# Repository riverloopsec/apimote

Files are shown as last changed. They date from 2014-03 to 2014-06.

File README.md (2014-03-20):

apimote
=======

ApiMote IEEE 802.15.4/ZigBee Sniffing Hardware

The ApiMote v4beta version is beta hardware intended for researchers,
students, utility companies, etc. to use for learning about and 
evaluating the security of IEEE 802.15.4/ZigBee systems as authorized.

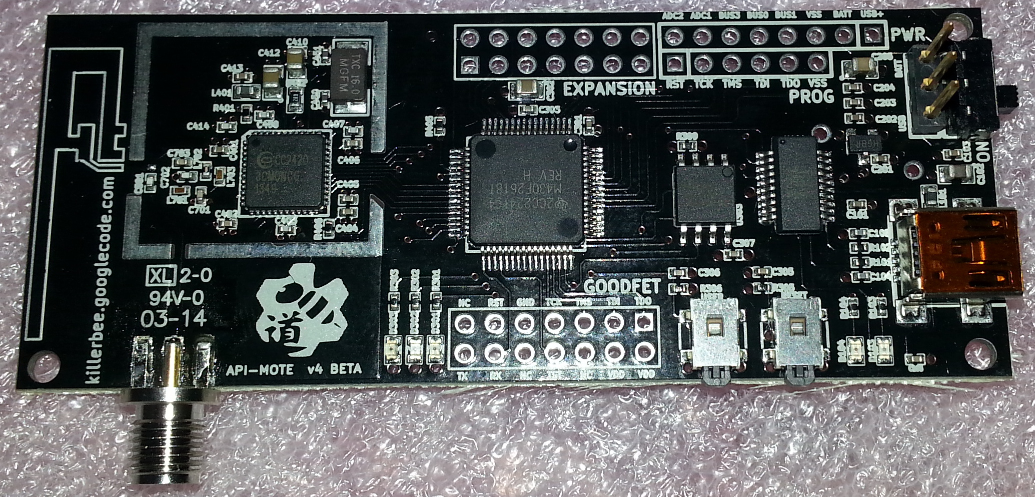
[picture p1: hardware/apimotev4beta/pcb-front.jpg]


----

The design files are created in KiCad, and we reccomend opening them in
the latest version.

----
Copyright 2013-2014 River Loop Security, LLC
Released as Open-Source Hardware under the LICENSE.txt terms.
You *must* use this hardware (and any accompanying software) as authorized
by law, and it is provided pursuint to those terms. We *are not* responsible
for any unauthorized or illegal use of this research tool.

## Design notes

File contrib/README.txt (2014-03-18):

We welcome contributions, additions, etc.

The ApiMote is specifically designed to expose pins for
both the microcontroller as well as power planes to allow
for expanded capabilities such as "shields" and battery packs.

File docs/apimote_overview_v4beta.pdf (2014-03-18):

Api-Do Project

# Api-Mote

Base r4.0beta

February 4, 2014

## 1 Product Description

Api-Mote is a low-power wireless module supporting IEEE 802.15.4. It allows for rapid application prototyping as well as wireless and security research. It leverages industry-standard chips including the MSP430 microprocessor and an IEEE 802.15.4 and ZigBee-ready RF transceiver. These main ICs provide a mix of ease-of-use/development with common wireless RF and security research frameworks as well as low-level hardware access (such as provided by the CC2420 compared to other models). Capability for expansion is designed into the Api-Mote Base , with two expansion headers, a battery-board/expansion header, and the option of an internal (PCB) or external (SMA-connected) antenna.

## 2 Key Features

- 2.4 GHz IEEE 802.15.4 Compliant and ZigBeeTMReady RF Transceiver (CC2420)
- Interoperability with other IEEE 802.15.4 devices
- 16-Bit Ultra-Low-Power MCU (116kB Flash, 8KB RAM) (MSP430F2618), featuring Integrated ADC, DAC, Supply Voltage Supervisor, and DMA Controller
- FTDI USB-to-Serial IC
- Programming and data collection via USB
- Integrated onboard antenna
- Low current consumption
- Hardware link-layer encryption and authentication is supported
- Optional SMA antenna connector
- Basic GoodFET-based firmware support is already available (TinyOS support should be easy)

## Contents

1 Product Description | 1
2 Key Features | 1
3 Module Description | 3
4 Microprocessor | 3
5 Radio | 6
6 Memory | 7
7 Expansion Connectors | 7
8 License | 8
9 Ordering/Contact Information | 8


Figure 1: Api-Mote Base 4.0beta Front

## 3 Module Description

The Api-Mote features a number of components in the standard board population, which is depicted in Figures 1 and 2:

### 3.1 Block Diagram

The Api-Mote Base standard components and their logical connections are shown at a highlevel in Figure 3:

## 4 Microprocessor

### 4.1 Description

The Api-Mote Base uses a TI MSP430F2618 micro-controller, part of the MSP430 family of ultralow-power micro-controllers. The architecture has five low-power modes optimized to achieve extended battery life in portable applications. The device features a powerful 16-bit RISC CPU, 16-bit registers, and constant generators. The calibrated digitally controlled oscillator (DCO) allows wake-up from low-power modes to active mode in less than 1 s. The MSP430F261x series has two built-in 16-bit timers, a fast 12-bit A/D converter, a comparator, dual 12-bit D/A converters, four universal serial communication interface (USCI) modules, DMA, and up to 64 I/O pins. Of these, up to 48 are available on the Api-Mote Base as I/O pins, as the rest are for dedicated functions (JTAG, Vdd/Vss, crystals, etc).
For more detailed information on the micro-controller, please refer to http://www.ti.com/
product/msp430f2618. (http://www.ti.com/product/msp430f2618)

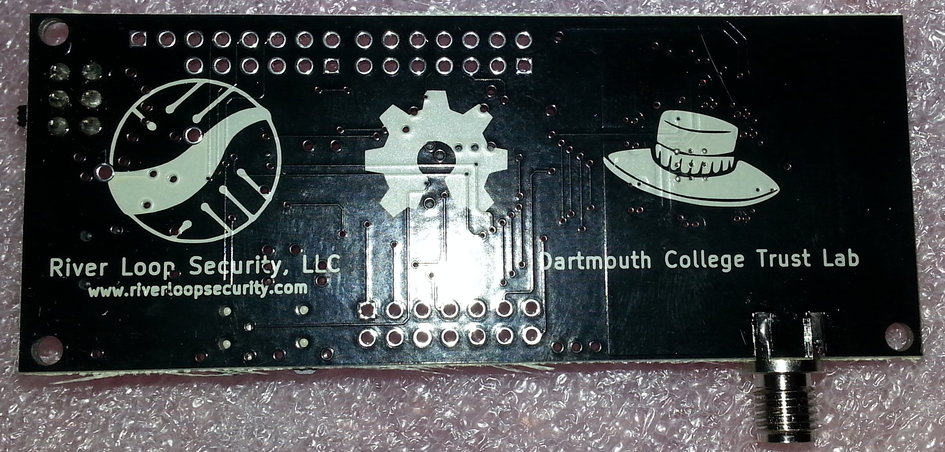
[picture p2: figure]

Figure 2: Api-Mote Base 4.0beta Back

### 4.2 Computer Communication

The Api-Mote uses an FTDI USB controller to communicate with the host computer. In order to communicate with the Api-Mote , the FTDI drivers must be installed on the host. These are often installed by default, but otherwise can be downloaded from FTDI’s website at: http://www.ftdichip.com. The Api-Mote appears as a COM port in Windows’ device manager or as a device in /dev in Linux, OSX, etc (see lsusb or dmesg). An application may communicate with the Api-Mote by opening the COM port or serial device assigned to the Api-Mote . Api-Mote communicates with the host computer through USART1 on the TI MSP430.
The Api-Mote uses a modern FTDI chip, and a newer Linux kernel is needed for built-in support. If you’re using Linux and you see the device in lsusb but don’t see the device appear in /dev/ttyUSB*, then this may be the issue. We’ve tested with 3.2.0-26-generic (on Ubuntu 12.04) among other kernels.

### 4.3 Programming

The Api-Mote revision 4.0beta can be wired either with direct access to chip programming using the FTDI DTR and RTS pins tied to the TCLK and RST pins on the MSP430, or may instead use an optional PIC micro-controller with special code to enable programming mode on the MSP430 after receiving a special command sequence. Unless otherwise specified, we discuss the Api-Mote Base with the direct programming mode. This is most closely compared to the GoodFET41’s wiring for programming (but with a different UART being used). Firmware images must be programmed and compiled for this specific architecture and hardware layout/pins. The programming is intended to be done using the patched BSL loader in the GoodFET trunk. Bootloading can be invoked as follows:

./goodfet.bsl --speed=38400 -p apimote4.hex

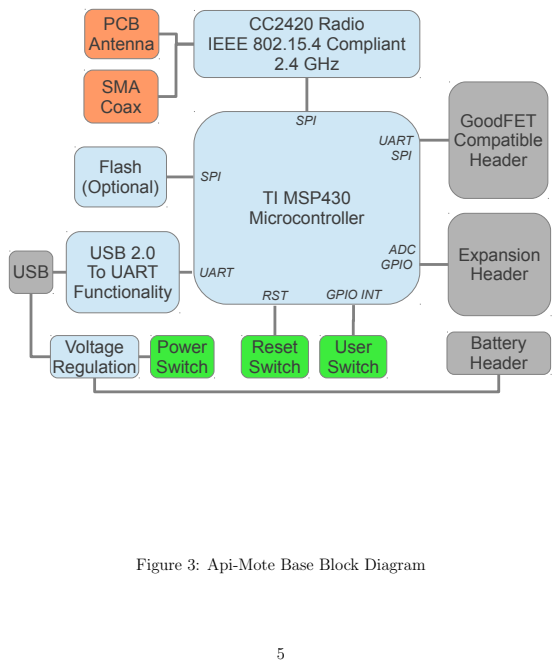
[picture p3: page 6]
CC2420 Radio IEEE 802.15.4 Compliant 2.4 GHz; PCB Antenna; SMA Coax; TI MSP430 Microcontroller; USB 2.0 To UART Functionality; Flash (Optional); GoodFET Compatible Header; Expansion Header; Reset Switch; User Switch; Power Switch; SPI; UART SPI; ADC GPIO UART; RST; GPIO INT; Voltage Regulation; USB; Battery Header

Figure 3: Api-Mote Base Block Diagram

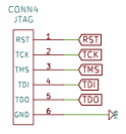
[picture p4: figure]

Figure 4: Programming/JTAG Header

If you need to compile modifications to the firmware, we show the compilation of the GoodFET trunk firmware for this board as an example:

$ cd goodfet/trunk/firmware
$ export board=apimote2
$ make clean install
$ ../client/goodfet.bsl --speed=38400 -p goodfet.hex

Note: The firmware for ApiMote 2, 3, and 4 is currently the same. Although currently compiled with board set to apimote2, the firmware is optimized for Api-Mote 4.0beta boards. They should work on ApiMote r2, boards, with the exception of the 3 user LEDs being controlled backwards (off turns them on, and visa versa).

### 4.3.1 Advanced Programming Access

The Api-Mote Base provides a programming header offering access to the MSP430’s JTAG pins, as shown in Figure 4.

## 5 Radio

Api-Mote features the Chipcon CC2420 radio for wireless communications. The CC2420 is an IEEE 802.15.4 compliant radio providing the PHY and some MAC functions.
The CC2420 is highly configurable for many applications with the default radio settings providing IEEE 802.15.4 compliance. It also has programmable output power. More information on the CC2420 is available in Chipcon’s datasheet at http://www.ti.com/product/
cc2420. (http://www.ti.com/product/cc2420)
The CC2420 is controlled by the TI MSP430 micro-controller through the SPI port and a series of digital I/O lines and interrupts. The radio may be shut off by the micro-controller for low power duty cycled operation.
The CC2420 provides a digital received signal strength indicator (RSSI) that may be read any time. Also, on each packet reception, the CC2420 samples the first eight chips, calculates

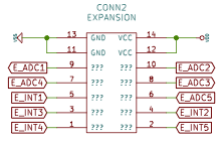
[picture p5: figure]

Figure 5: Expansion Header

the error rate, and produces a link quality indication (LQI) value that may optionally be included with each received packet.

## 6 Memory

The Api-Mote Base has support for external memory (rather than what is contained in the MCU), specifically a flash chip mounted on the board. This is available by SPI, and is specified as a 32M flash IC. Currently, support for this chip is not in the GoodFET firmware. Please feel free to add it! Note, it is connected on a separate SPI bus than the radio.

## 7 Expansion Connectors

The Api-Mote Base has three expansion connectors. These are detailed below:

### 7.1 Expansion Header

The Api-Mote Base provides a 7-by-2 header meant to enable additional external devices such as sensors, LCD displays, user I/O, and peripherals can be controlled. The pinout of this header is shown in Figure 5.

### 7.2 GoodFET Header

The Api-Mote Base provides a 7-by-2 header that is intended to be compatible with the headers common on GoodFET boards. GoodFET firmware images which seek this compatibility should setup this header as shown in Figure 6.

### 7.3 Battery Header

The Api-Mote Base is designed to operate on battery power, and has a 8-by-1 header to support the addition of a custom battery pack that provides advanced power regulation,

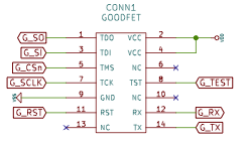
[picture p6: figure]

Figure 6: GoodFET Header

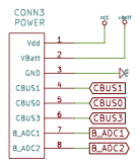
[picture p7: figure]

Figure 7: Battery Header

sleep, and recharge capabilities. The pinout of this header is shown in Figure 7. The Api-Mote Base USB-to-serial IC supports high current USB port detection for decreased charge time. At this time, Api-Mote Base revision 4.0beta does not yet have a complementary battery pack, but one is under development.

## 8 License

This product is released by River Loop Security as an open-source project. The hardware designs and firmware are freely available. However, we ask that one does not sell products based on this device without first obtaining written permission. Collaboration, however, is always welcome and we strongly encourage people to help develop the firmware, etc. Please contact us if you have questions.

## 9 Ordering/Contact Information

To request an Api-Mote, please visit http://rmspeers.com/contact/pcb-requests. For more information, please contact us at team@riverloopsecurity.com.

## Acknowledgements

The Api-Mote Base project lead, Ryan Speers, extends many thanks to the board engineer and designer, Javier Vazquez, as well as the original Api-Mote v1 engineer. Also, much credit and thanks goes to Professor Sergey Bratus of Dartmouth College for his encouragement and funding of the test runs of production. Thank you to River Loop Security for supporting this project with time and funding. Finally, thanks goes to Travis Goodspeed, Ricky Melgares, and Michael Ossmann for their ongoing collaboration with hardware and ZigBee security research.

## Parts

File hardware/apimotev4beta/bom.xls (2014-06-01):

Quantity | Reference(s) | Footprint | Value | Mfg | Mfg Part | Notes
2 | C701, C703 | SM0402 | 0.5pF | AVX | 04025A0R5CAT2A
2 | C501, C702 | SM0402 | 5.6pF | AVX | 04025U5R6CAT2A
1 | J101 | CUSTOM | N/A | FCI | 10033526-N3212MLF
1 | ANT1 | RP-SMA | N/A | Amphenol | 132136RP | Optional part; or Molex 73391-0320
2 | SW305, SW306 | SPST NO M | N/A | TE Connectivity / Alcoswitch | 1571262-2
1 | JMP201 | SIL-3 (0.1”) | N/A | FCI | 69190-403
1 | Y450 | SM2010 | 16MHz | TXC | 7A-16.000MAAJ-T
1 | L702 | SM0402 | 5.6nH | Abracon | ATFC-0402-5N6-B-T
2 | L101, L401 | SM0603 | 600R/2A | Murata | BLM18KG601SN1D
4 | C205, C302, C410, C412 | SM0805 | 10uF | TDK | C2012X5R1A106K125AB and C2012X5R1A106K/1.25
1 | U401 | QFN-48 | N/A | TI | CC2420
2 | C104, C105 | SM0402 | 47pF | TDK | CGA2B2C0G1H470J
2 | R101, R102 | SM0402 | 27R | Bourns | CR0402-JW-270GLF
1 | R309 | SM0402 | 10K | Visahy | CRCW040210K0JNED
5 | R305, R306, R401, R405, R406 | SM0402 | 43K 1% | Visahy | CRCW040243K0FKED
1 | R402 | SM0603 | 2R | Visahy | CRCW06032R00JNTA / CRCW06032R00JNEA
1 | U101 | SSOP-20 | N/A | FTDI | FT231XS-R
2 | C450, C451 | SM0402 | 27pF | Murata | GRM1555C1H270GA01D
4 | C403, C407, C408, C414 | SM0402 | 68pF | Murata | GRM1555C1H680JA01D
2 | C201, C202 | SM0402 | 1uF | Murata | GRM155R61A105KE15D
12 | C101, C103, C203, C204, C301, C303, C307, C401, C404, C405, C406, C413 | SM0402 | 0.1uF | Murata | GRM155R71A104JA01D
2 | C305, C306 | SM0402 | 2.2nF | Murata | GRM155R71H222KA01D
2 | L701, L703 | SM0402 | 7.5nH | Murata | LQP15MN7N5B02D
1 | U201 | SOT-23A | N/A | Microchip | MCP1702T-3302E/CB
5 | R103, R104, R301, R302, R303 | SM0402 | 330R | Rohm Semiconductor | MCR01MRTF3300
1 | SW201 | SIL-3 (0.1”) | N/A | Apem | MHSS1105
1 | JMP202 | 0.1” Pitch | N/A | Adam Tech | MSA-G
1 | U301 | QFP-64 | N/A | TI | MSP430F2618TPM
Opt | U303 | SOIC-8 | N/A | Microchip | SST25VF032B-80-4I-S2AF | Optional part
2 | C106, C402 | SM0402 | 10nF | Visahy | VJ0402Y103JXXCW1BC
1 | C102 | SM0805 | 4.7uF | Visahy | VJ0805V475MXQTW1BC
2 | D103, D302 | SM0603 | GREEN | Visahy | VLMG1300-GS08
2 | D104, D303 | SM0603 | RED | Visahy | VLMS1300-GS08
1 | D301 | SM0603 | YELLOW | Visahy | VLMY1300-GS08
Opt | Headers | 1 row strips |  | 3M | 929834-02-36-RK
Opt | Headers | 2 x 7 pins |  | 3M | 929836-01-07-RK
1 | JMP202 | 2 PIN SHUNT

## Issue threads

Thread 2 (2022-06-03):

how to connect to kali with apimote

Jungjungjungjung, 2022-06-03:
hi , i have installed the killerbee in my kali linux and connect the apimote to my laptop . the issue is when i run zbid , it wont show the apimote that i connected
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

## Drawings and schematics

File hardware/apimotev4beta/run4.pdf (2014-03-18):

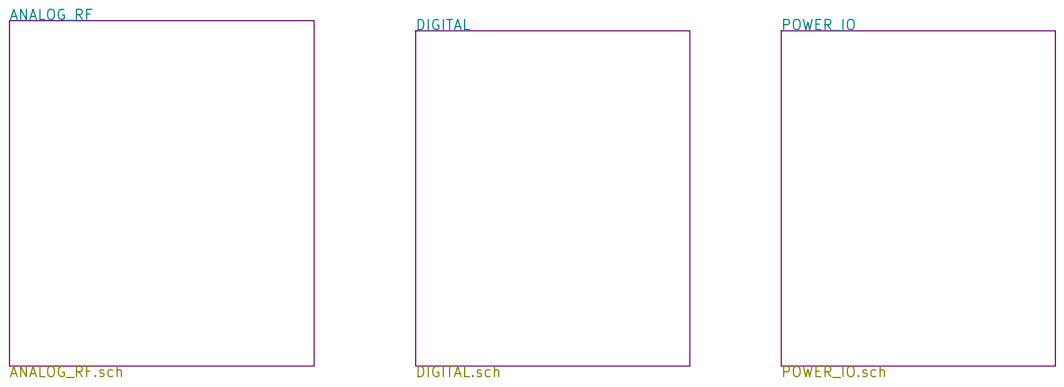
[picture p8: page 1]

POWER_IO.sch DIGITAL DIGITAL.sch ANALOG_RF ANALOG_RF.sch

C Sheet: /home/devops/Dropbox/apimote/run4-kicad/run4.sch File: Title:

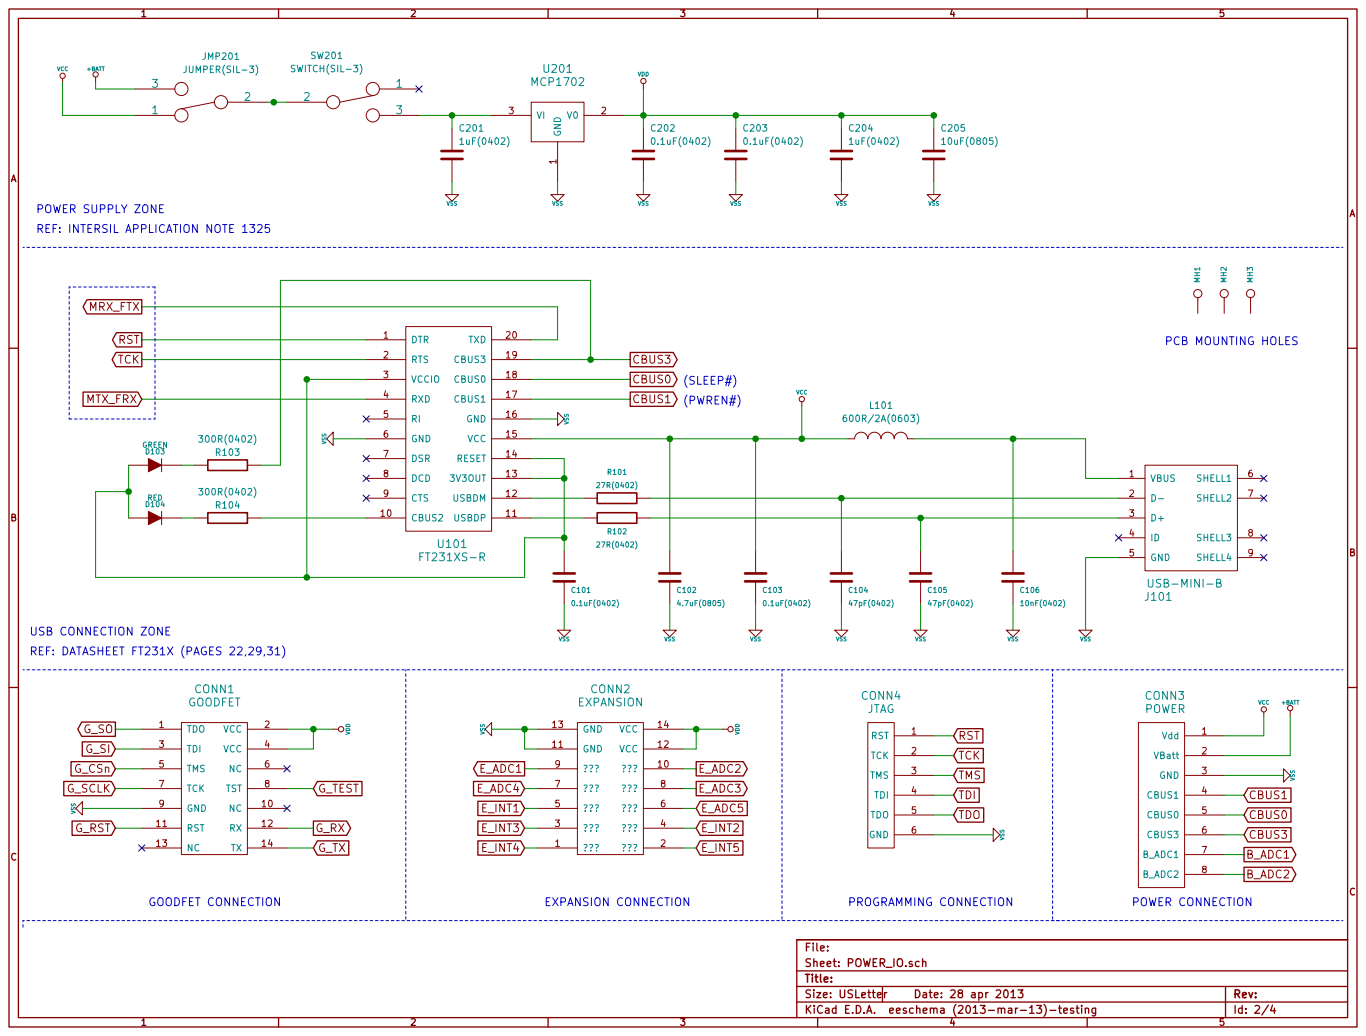
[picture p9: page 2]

C Sheet: POWER_IO.sch File: Title:

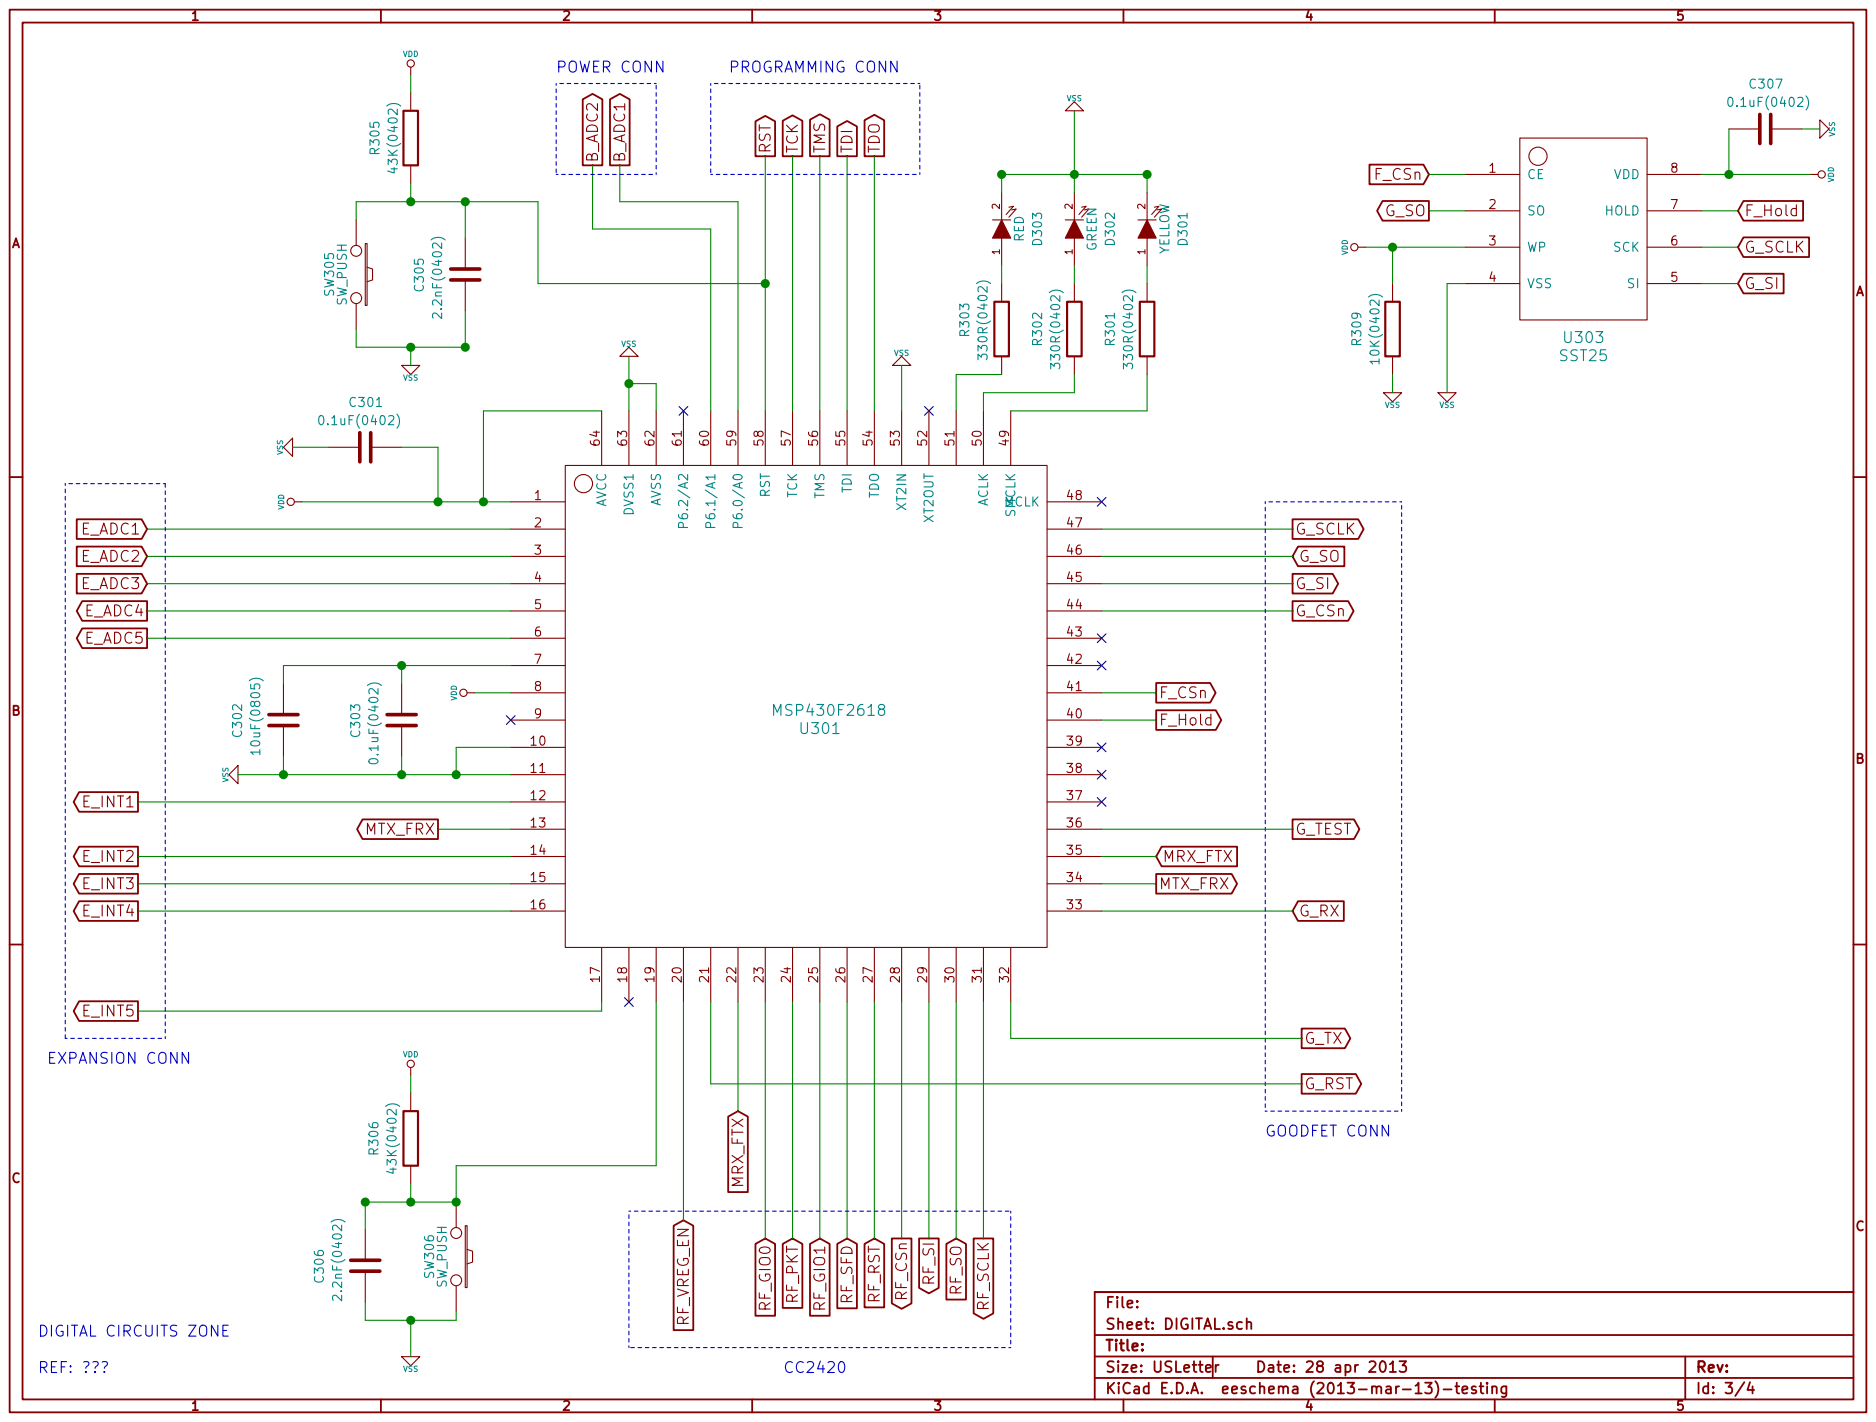
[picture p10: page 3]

C Sheet: DIGITAL.sch File: Title:

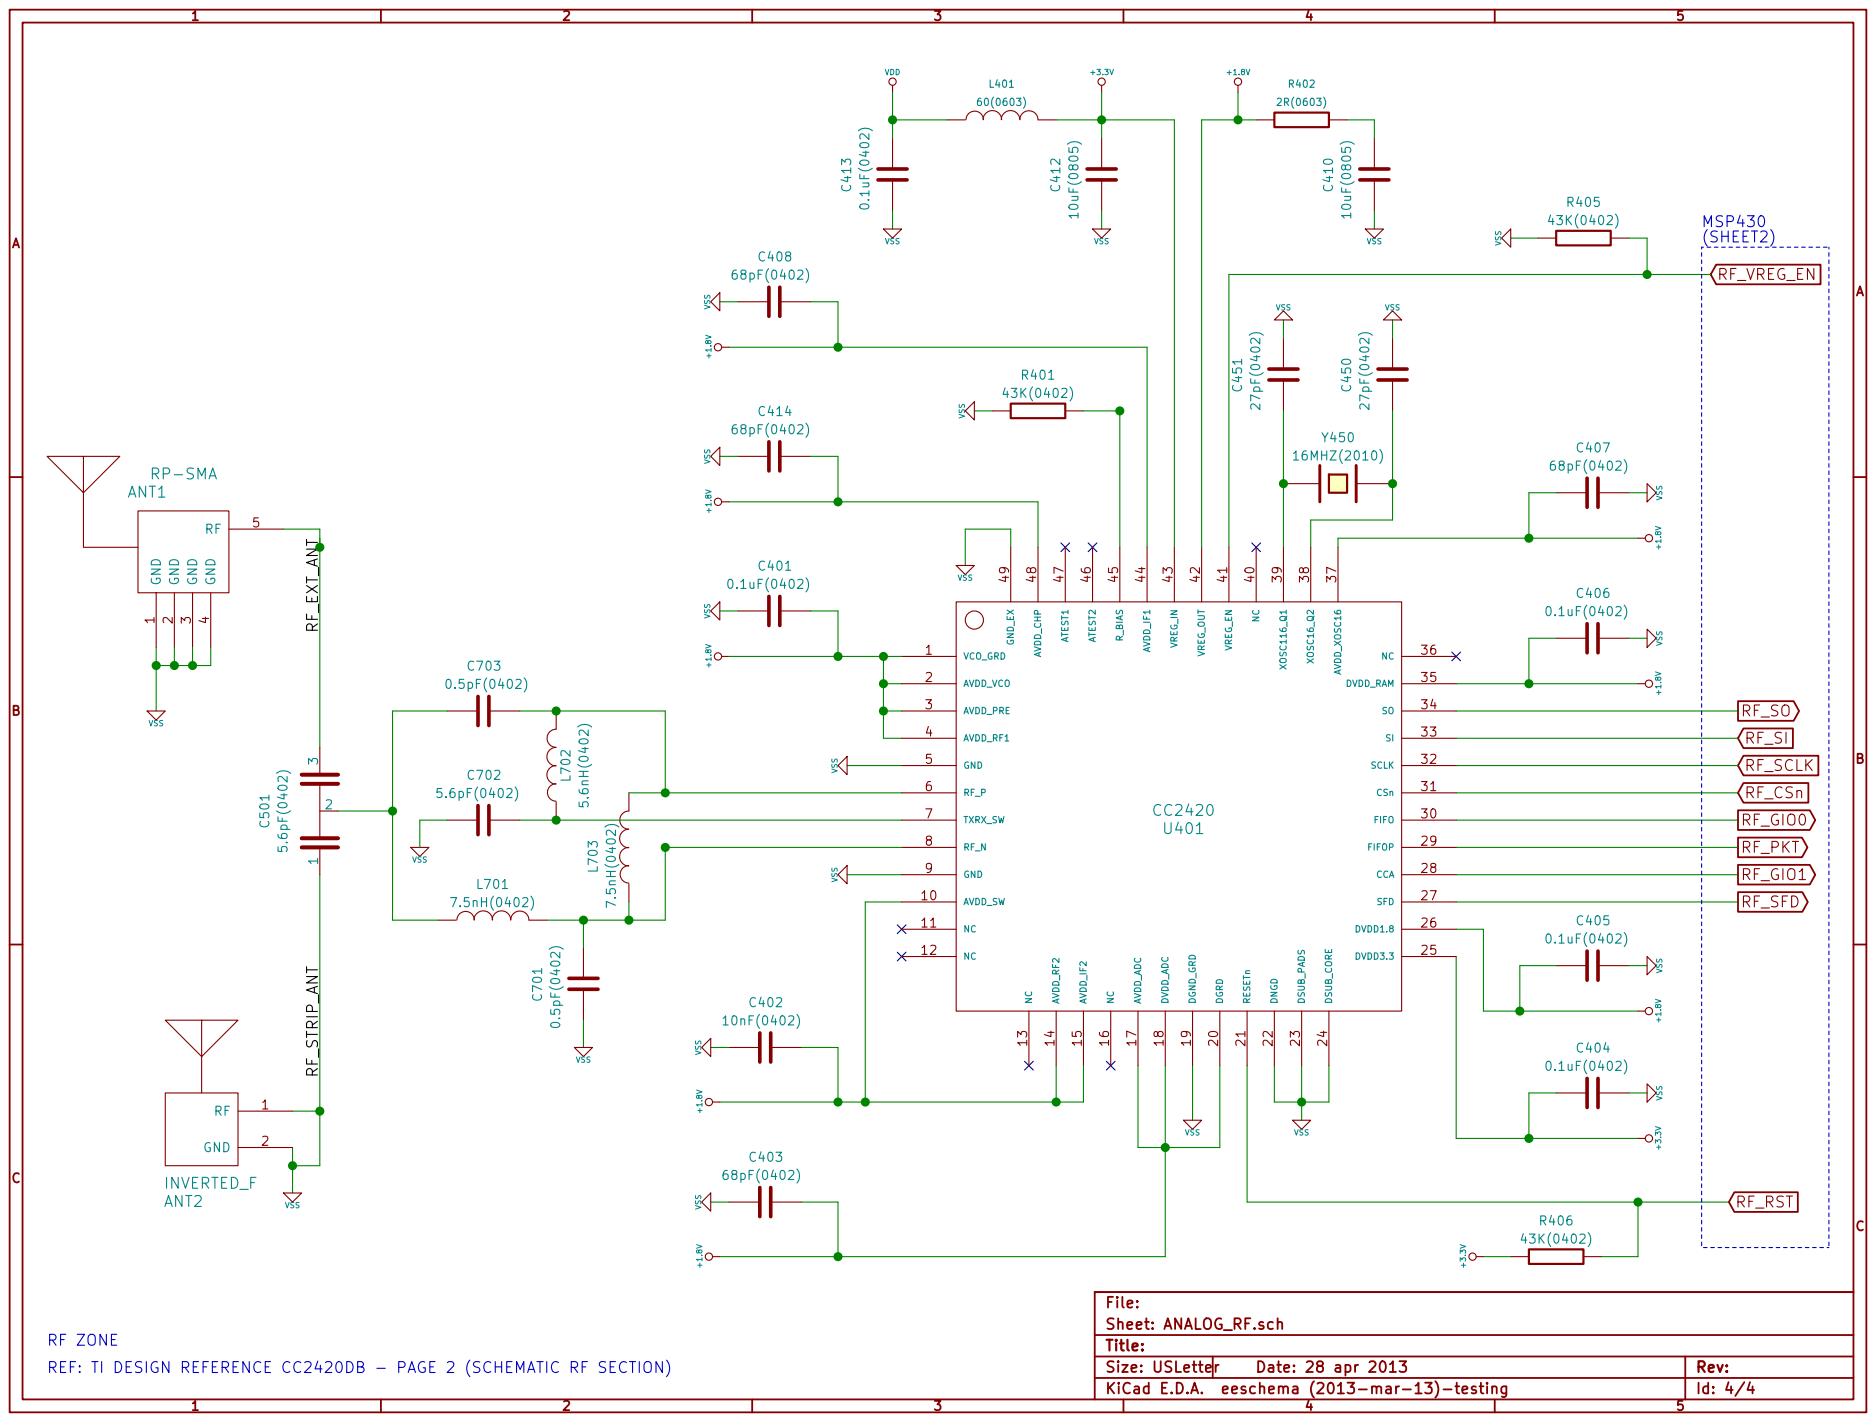
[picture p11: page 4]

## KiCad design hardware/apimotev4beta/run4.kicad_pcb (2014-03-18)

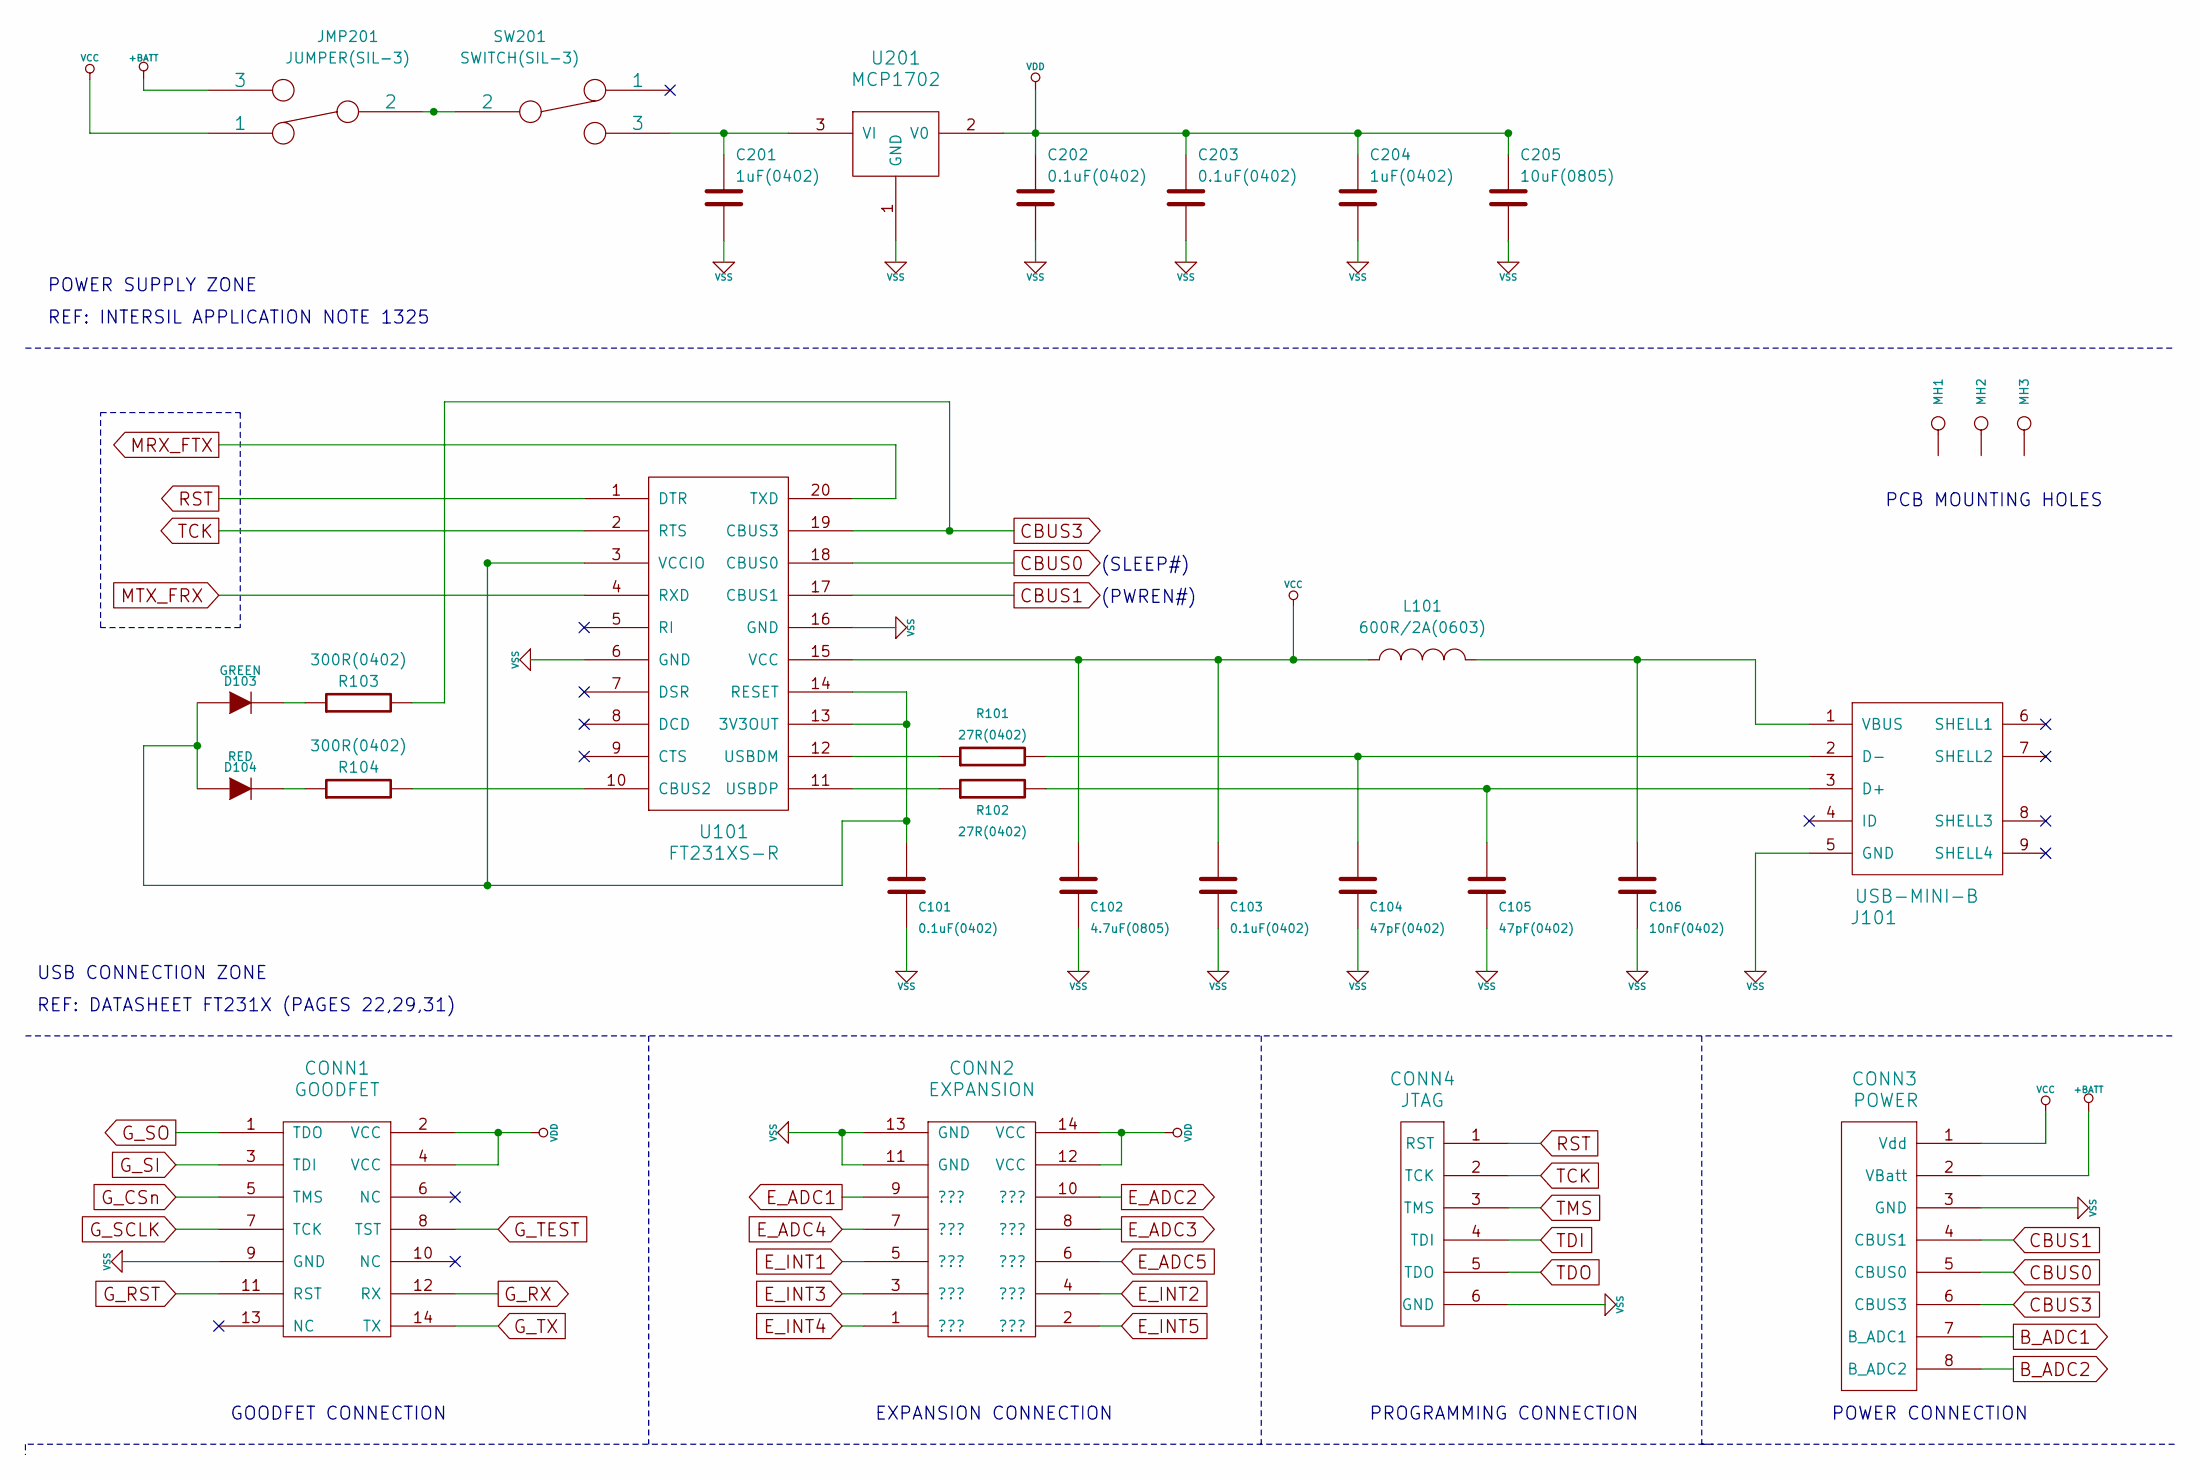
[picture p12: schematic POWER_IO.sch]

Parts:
C101, C103: 0.1uF(0402)
C102: 4.7uF(0805)
C104, C105: 47pF(0402)
C106: 10nF(0402)
C201, C204: 1uF(0402)
C202, C203: 0.1uF(0402)
C205: 10uF(0805)
CONN1: GOODFET
CONN2: EXPANSION
CONN3: POWER
CONN4: JTAG
D103: GREEN
D104: RED
J101: USB-MINI-B
JMP201: JUMPER(SIL-3)
L101: 600R/2A(0603)
MH1, MH2, MH3: Xmm
R101, R102: 27R(0402)
R103, R104: 300R(0402)
SW201: SWITCH(SIL-3)
U101: FT231XS-R
U201: MCP1702

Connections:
+BATT: CONN3.2 (VBatt), JMP201.3
B_ADC1: CONN3.7 (B_ADC1); also elsewhere on the board
B_ADC2: CONN3.8 (B_ADC2); also elsewhere on the board
CBUS0: CONN3.5 (CBUS0), U101.18 (CBUS0)
CBUS1: CONN3.4 (CBUS1), U101.17 (CBUS1)
CBUS3: CONN3.6 (CBUS3), R103.2, U101.19 (CBUS3)
E_ADC1: CONN2.9 (???); also elsewhere on the board
E_ADC2: CONN2.10 (???); also elsewhere on the board
E_ADC3: CONN2.8 (???); also elsewhere on the board
E_ADC4: CONN2.7 (???); also elsewhere on the board
E_ADC5: CONN2.6 (???); also elsewhere on the board
E_INT1: CONN2.5 (???); also elsewhere on the board
E_INT2: CONN2.4 (???); also elsewhere on the board
E_INT3: CONN2.3 (???); also elsewhere on the board
E_INT4: CONN2.1 (???); also elsewhere on the board
E_INT5: CONN2.2 (???); also elsewhere on the board
G_CSn: CONN1.5 (TMS); also elsewhere on the board
G_RST: CONN1.11 (RST); also elsewhere on the board
G_RX: CONN1.12 (RX); also elsewhere on the board
G_SCLK: CONN1.7 (TCK); also elsewhere on the board
G_SI: CONN1.3 (TDI); also elsewhere on the board
G_SO: CONN1.1 (TDO); also elsewhere on the board
G_TEST: CONN1.8 (TST); also elsewhere on the board
G_TX: CONN1.14 (TX); also elsewhere on the board
MRX_FTX: U101.20 (TXD); also elsewhere on the board
MTX_FRX: U101.4 (RXD); also elsewhere on the board
unnamed: C105.1, J101.3 (D+), R102.2
unnamed: C104.1, J101.2 (D-), R101.2
unnamed: JMP201.2, SW201.2
unnamed: R104.2, U101.10 (CBUS2)
unnamed: C101.1, D103.1 (A), D104.1 (A), U101.3 (VCCIO), U101.13 (3V3OUT), U101.14 (RESET)
unnamed: R102.1, U101.11 (USBDP)
unnamed: R101.1, U101.12 (USBDM)
unnamed: C106.1, J101.1 (VBUS), L101.2
unnamed: D103.2 (K), R103.1
unnamed: D104.2 (K), R104.1
unnamed 54: C201.1, SW201.3, U201.3 (VI); also elsewhere on the board
RST: CONN4.1 (RST), U101.1 (DTR); also elsewhere on the board
TCK: CONN4.2 (TCK), U101.2 (RTS); also elsewhere on the board
TDI: CONN4.4 (TDI); also elsewhere on the board
TDO: CONN4.5 (TDO); also elsewhere on the board
TMS: CONN4.3 (TMS); also elsewhere on the board
VCC: C102.1, C103.1, CONN3.1 (Vdd), JMP201.1, L101.1, U101.15 (VCC)
VDD: C202.1, C203.1, C204.1, C205.1, CONN1.2 (VCC), CONN1.4 (VCC), CONN2.12 (VCC), CONN2.14 (VCC), U201.2 (V0); also elsewhere on the board
VSS: C101.2, C102.2, C103.2, C104.2, C105.2, C106.2, C201.2, C202.2, C203.2, C204.2, C205.2, CONN1.9 (GND), CONN2.11 (GND), CONN2.13 (GND), CONN3.3 (GND), CONN4.6 (GND), J101.5 (GND), U101.6 (GND), U101.16 (GND), U201.1 (GND); also elsewhere on the board

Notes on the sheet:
POWER SUPPLY ZONE
USB CONNECTION ZONE
GOODFET CONNECTION
EXPANSION CONNECTION
PROGRAMMING CONNECTION
POWER CONNECTION
(SLEEP#)
(PWREN#)
REF: INTERSIL APPLICATION NOTE 1325
REF: DATASHEET FT231X (PAGES 22,29,31)
PCB MOUNTING HOLES

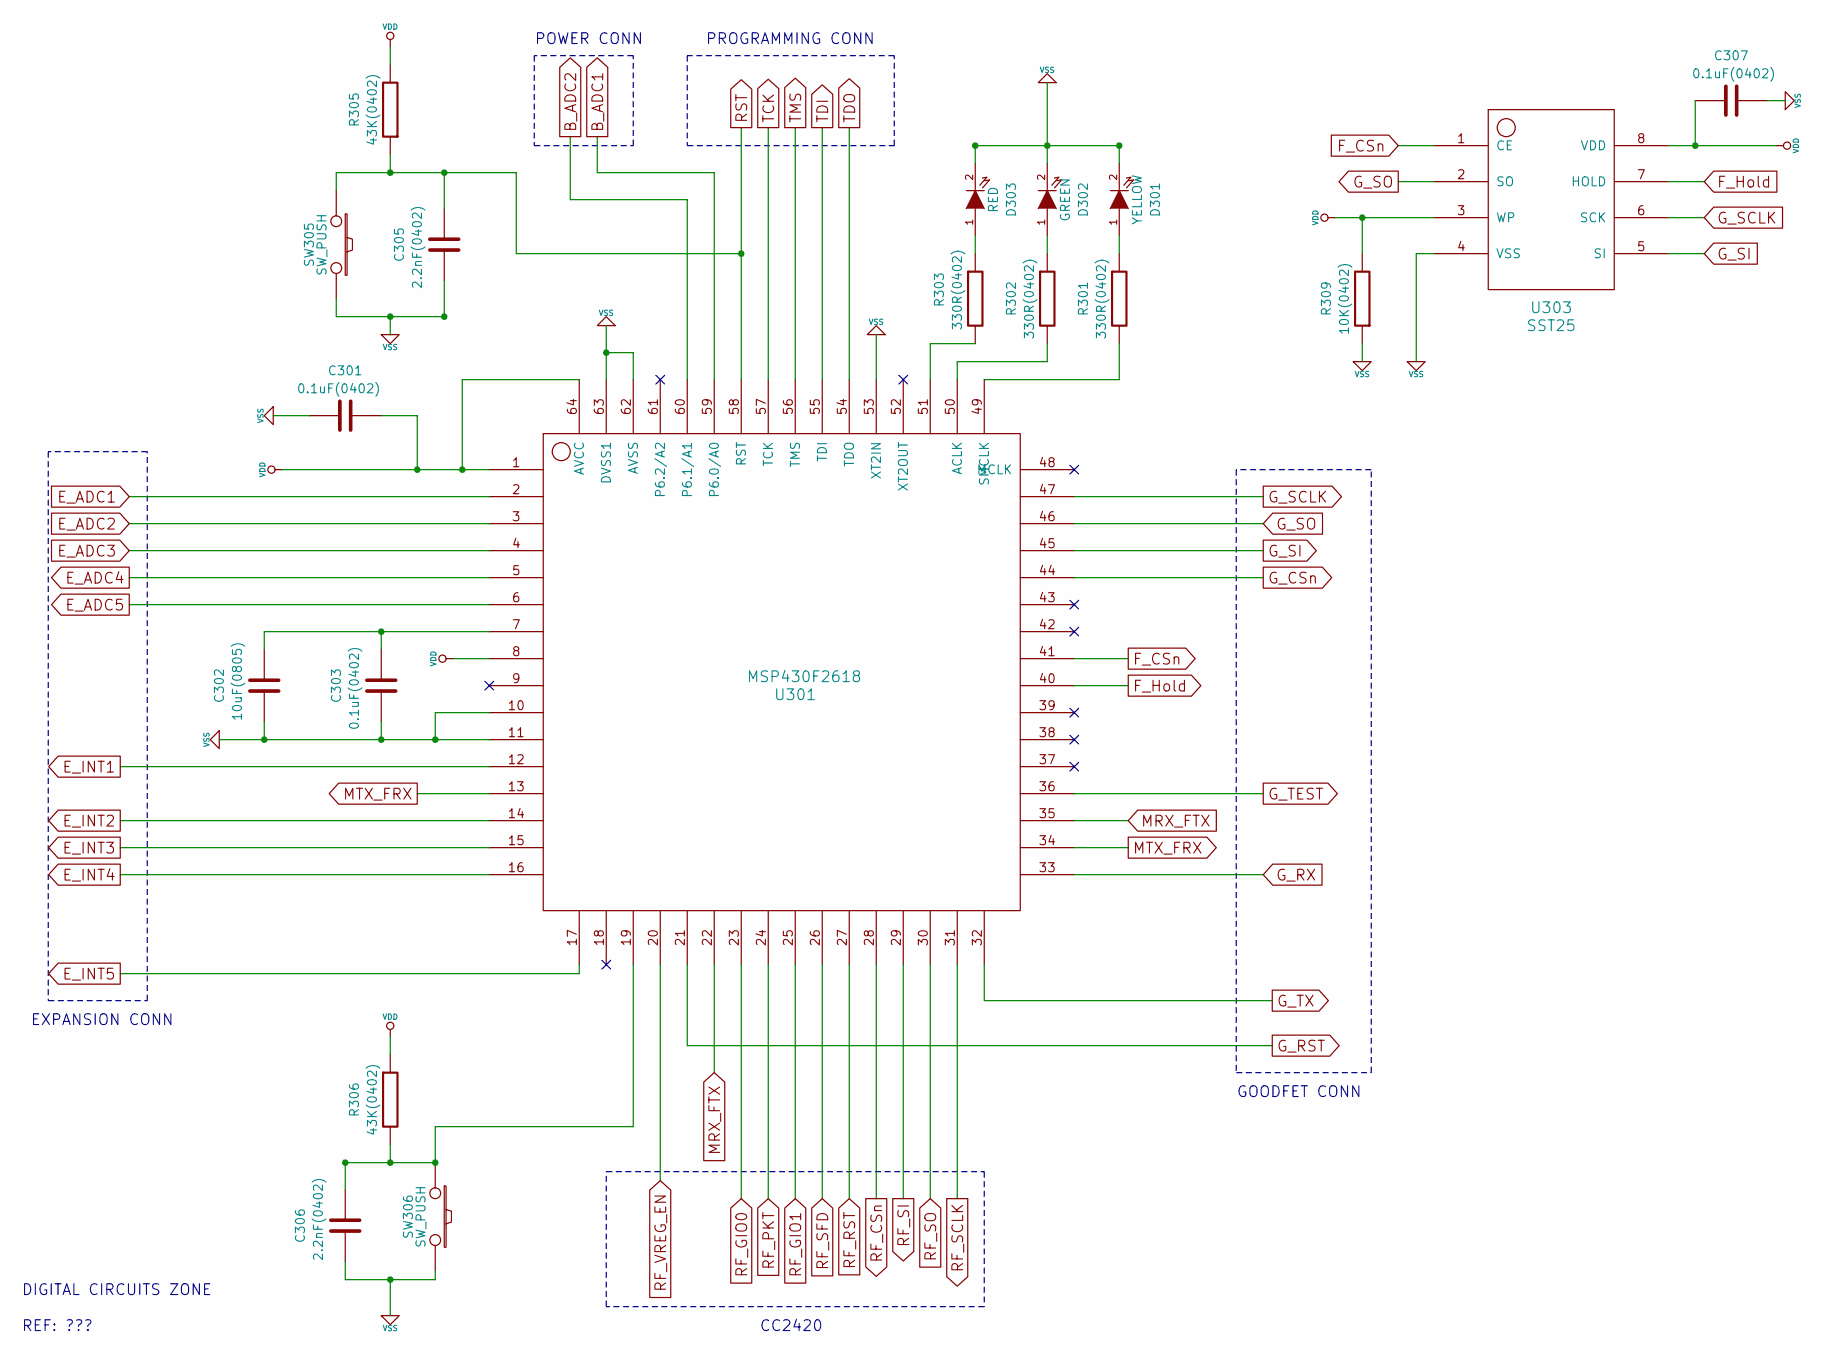
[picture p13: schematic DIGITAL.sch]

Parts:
C301, C303, C307: 0.1uF(0402)
C302: 10uF(0805)
C305, C306: 2.2nF(0402)
D301: YELLOW
D302: GREEN
D303: RED
R301, R302, R303: 330R(0402)
R305, R306: 43K(0402)
R309: 10K(0402)
SW305, SW306: SW_PUSH
U301: MSP430F2618
U303: SST25

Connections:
B_ADC1: U301.59 (P6.0/A0); also elsewhere on the board
B_ADC2: U301.60 (P6.1/A1); also elsewhere on the board
E_ADC1: U301.2; also elsewhere on the board
E_ADC2: U301.3; also elsewhere on the board
E_ADC3: U301.4; also elsewhere on the board
E_ADC4: U301.5; also elsewhere on the board
E_ADC5: U301.6; also elsewhere on the board
E_INT1: U301.12; also elsewhere on the board
E_INT2: U301.14; also elsewhere on the board
E_INT3: U301.15; also elsewhere on the board
E_INT4: U301.16; also elsewhere on the board
E_INT5: U301.17; also elsewhere on the board
F_CSn: U301.41, U303.1 (CE)
F_Hold: U301.40, U303.7 (HOLD)
G_CSn: U301.44; also elsewhere on the board
G_RST: U301.21; also elsewhere on the board
G_RX: U301.33; also elsewhere on the board
G_SCLK: U301.47, U303.6 (SCK); also elsewhere on the board
G_SI: U301.45, U303.5 (SI); also elsewhere on the board
G_SO: U301.46, U303.2 (SO); also elsewhere on the board
G_TEST: U301.36; also elsewhere on the board
G_TX: U301.32; also elsewhere on the board
MRX_FTX: U301.22, U301.35; also elsewhere on the board
MTX_FRX: U301.13, U301.34; also elsewhere on the board
unnamed: C302.1, C303.1, U301.7
unnamed: R301.2, U301.49 (SMCLK)
unnamed: R303.2, U301.51
unnamed: R302.2, U301.50 (ACLK)
unnamed: D303.1 (A), R303.1
unnamed: D302.1 (A), R302.1
unnamed: D301.1 (A), R301.1
unnamed: C306.1, R306.2, SW306.1, U301.19
RF_CSn: U301.28; also elsewhere on the board
RF_GIO0: U301.23; also elsewhere on the board
RF_GIO1: U301.25; also elsewhere on the board
RF_PKT: U301.24; also elsewhere on the board
RF_RST: U301.27; also elsewhere on the board
RF_SCLK: U301.31; also elsewhere on the board
RF_SFD: U301.26; also elsewhere on the board
RF_SI: U301.29; also elsewhere on the board
RF_SO: U301.30; also elsewhere on the board
RF_VREG_EN: U301.20; also elsewhere on the board
RST: C305.1, R305.1, SW305.1, U301.58 (RST); also elsewhere on the board
TCK: U301.57 (TCK); also elsewhere on the board
TDI: U301.55 (TDI); also elsewhere on the board
TDO: U301.54 (TDO); also elsewhere on the board
TMS: U301.56 (TMS); also elsewhere on the board
VDD: C301.2, C307.1, R305.2, R306.1, R309.2, U301.1, U301.8, U301.64 (AVCC), U303.3 (WP), U303.8 (VDD); also elsewhere on the board
VSS: C301.1, C302.2, C303.2, C305.2, C306.2, C307.2, D301.2 (K), D302.2 (K), D303.2 (K), R309.1, SW305.2, SW306.2, U301.10, U301.11, U301.53 (XT2IN), U301.62 (AVSS), U301.63 (DVSS1), U303.4 (VSS); also elsewhere on the board

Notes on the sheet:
DIGITAL CIRCUITS ZONE
CC2420
GOODFET CONN
EXPANSION CONN
PROGRAMMING CONN
POWER CONN
REF: ???

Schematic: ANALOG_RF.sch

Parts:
ANT1: RP-SMA
ANT2: INVERTED_F
C401, C404, C405, C406, C413: 0.1uF(0402)
C402: 10nF(0402)
C403, C407, C408, C414: 68pF(0402)
C410, C412: 10uF(0805)
C450, C451: 27pF(0402)
C501, C702: 5.6pF(0402)
C701, C703: 0.5pF(0402)
L401: 60(0603)
L701, L703: 7.5nH(0402)
L702: 5.6nH(0402)
R401, R405, R406: 43K(0402)
R402: 2R(0603)
U401: CC2420
Y450: 16MHZ(2010)

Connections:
+1.8V: C401.2, C402.2, C403.2, C405.1, C406.1, C407.1, C408.2, C414.2, R402.1, U401.1 (VCO_GRD), U401.2 (AVDD_VCO), U401.3 (AVDD_PRE), U401.4 (AVDD_RF1), U401.10 (AVDD_SW), U401.14 (AVDD_RF2), U401.15 (AVDD_IF2), U401.17 (AVDD_ADC), U401.18 (DVDD_ADC), U401.20 (DGRD), U401.26 (DVDD1.8), U401.35 (DVDD_RAM), U401.37 (AVDD_XOSC16), U401.42 (VREG_OUT), U401.44 (AVDD_IF1), U401.48 (AVDD_CHP)
+3.3V: C404.1, C412.1, L401.2, R406.1, U401.25 (DVDD3.3), U401.43 (VREG_IN)
/ANALOG_RF/RF_EXT_ANT: ANT1.5 (RF), C501.3
unnamed: C410.1, R402.2
unnamed: C501.2, C703.1, L701.1
unnamed: C701.1, L701.2, L703.1, U401.8 (RF_N)
unnamed: R401.2, U401.45 (R_BIAS)
unnamed: C703.2, L702.2, L703.2, U401.6 (RF_P)
unnamed: C702.2, L702.1, U401.7 (TXRX_SW)
unnamed: C451.2, U401.39 (XOSC116_Q1), Y450.1
unnamed: C450.2, U401.38 (XOSC16_Q2), Y450.2
RF_CSn: U401.31 (CSn); also elsewhere on the board
RF_GIO0: U401.30 (FIFO); also elsewhere on the board
RF_GIO1: U401.28 (CCA); also elsewhere on the board
RF_PKT: U401.29 (FIFOP); also elsewhere on the board
RF_RST: R406.2, U401.21 (RESETn); also elsewhere on the board
RF_SCLK: U401.32 (SCLK); also elsewhere on the board
RF_SFD: U401.27 (SFD); also elsewhere on the board
RF_SI: U401.33 (SI); also elsewhere on the board
RF_SO: U401.34 (SO); also elsewhere on the board
RF_VREG_EN: R405.2, U401.41 (VREG_EN); also elsewhere on the board
VDD: C413.1, L401.1; also elsewhere on the board
VSS: ANT1.1 (GND), ANT1.2 (GND), ANT1.3 (GND), ANT1.4 (GND), ANT2.1 (RF), ANT2.2 (GND), C401.1, C402.1, C403.1, C404.2, C405.2, C406.2, C407.2, C408.1, C410.2, C412.2, C413.2, C414.1, C450.1, C451.1, C501.1, C701.2, C702.1, R401.1, R405.1, U401.5 (GND), U401.9 (GND), U401.19 (DGND_GRD), U401.22 (DNGD), U401.23 (DSUB_PADS), U401.24 (DSUB_CORE), U401.49 (GND_EX); also elsewhere on the board

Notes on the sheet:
RF ZONE
MSP430 (SHEET2)
REF: TI DESIGN REFERENCE CC2420DB - PAGE 2 (SCHEMATIC RF SECTION)

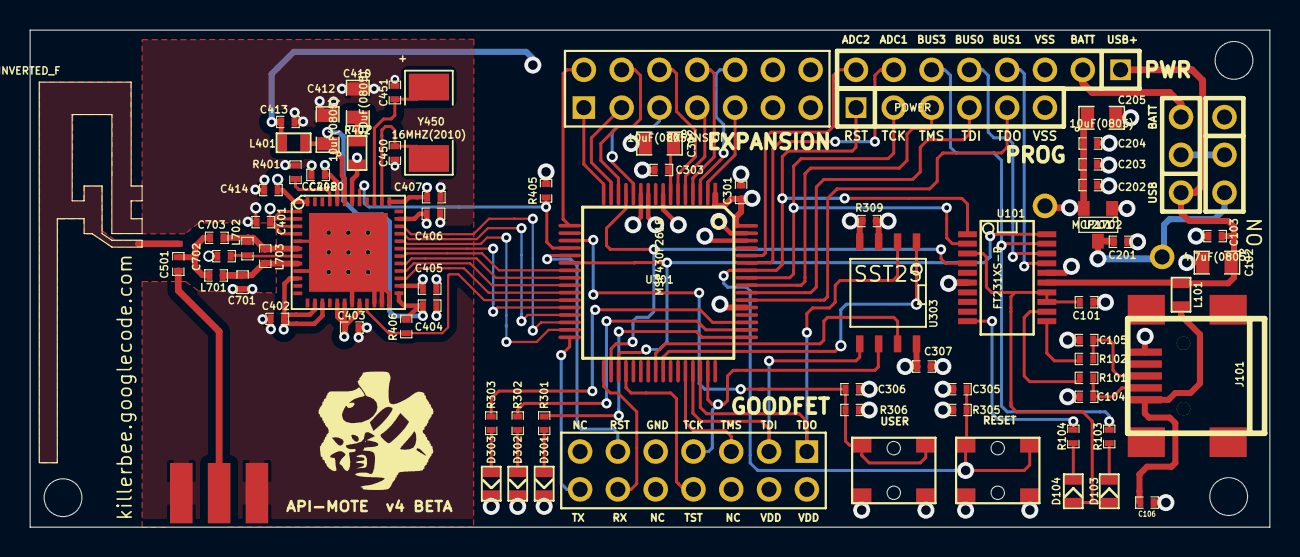
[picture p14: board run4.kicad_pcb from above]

Board: 4 copper layers, 83.3 x 33.4 mm, 83 parts (0 on the bottom side), 76 nets.

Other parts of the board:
PIN_ARRAY_1, PIN_ARRAY_1#2, PIN_ARRAY_1#3, PIN_ARRAY_1#4: Val**; TAP

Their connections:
unnamed 54: PIN_ARRAY_1#3.1; also elsewhere on the board
VDD: PIN_ARRAY_1#4.1; also elsewhere on the board

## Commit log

2014-03-18 apimote v4beta files added
    [ANALOG_RF.sch, DIGITAL.sch, POWER_IO.sch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]
2014-06-01 adding the apimote v4beta BOM
    [bom.xls]
